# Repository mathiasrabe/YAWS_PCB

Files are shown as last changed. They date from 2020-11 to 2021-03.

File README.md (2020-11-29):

# PCB for IOT weather station

This is the PCB of my small IOT weather station. The weatherstation consists of the following parts:

- ATtiny85 and LT1763-3.3 for power control
- TP4056 to charge the li-ion battery with solar
- BME280 to measure temperature, humidity and pressure
- ESP8266 to connect to WiFi and send the reedings via MQTT

## pictures

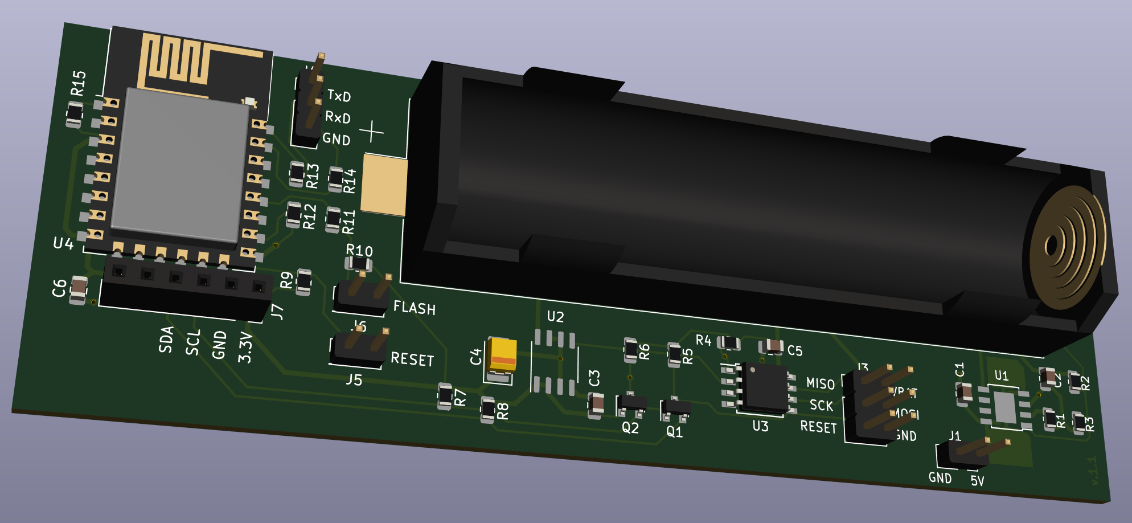
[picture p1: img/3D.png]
3D presentation

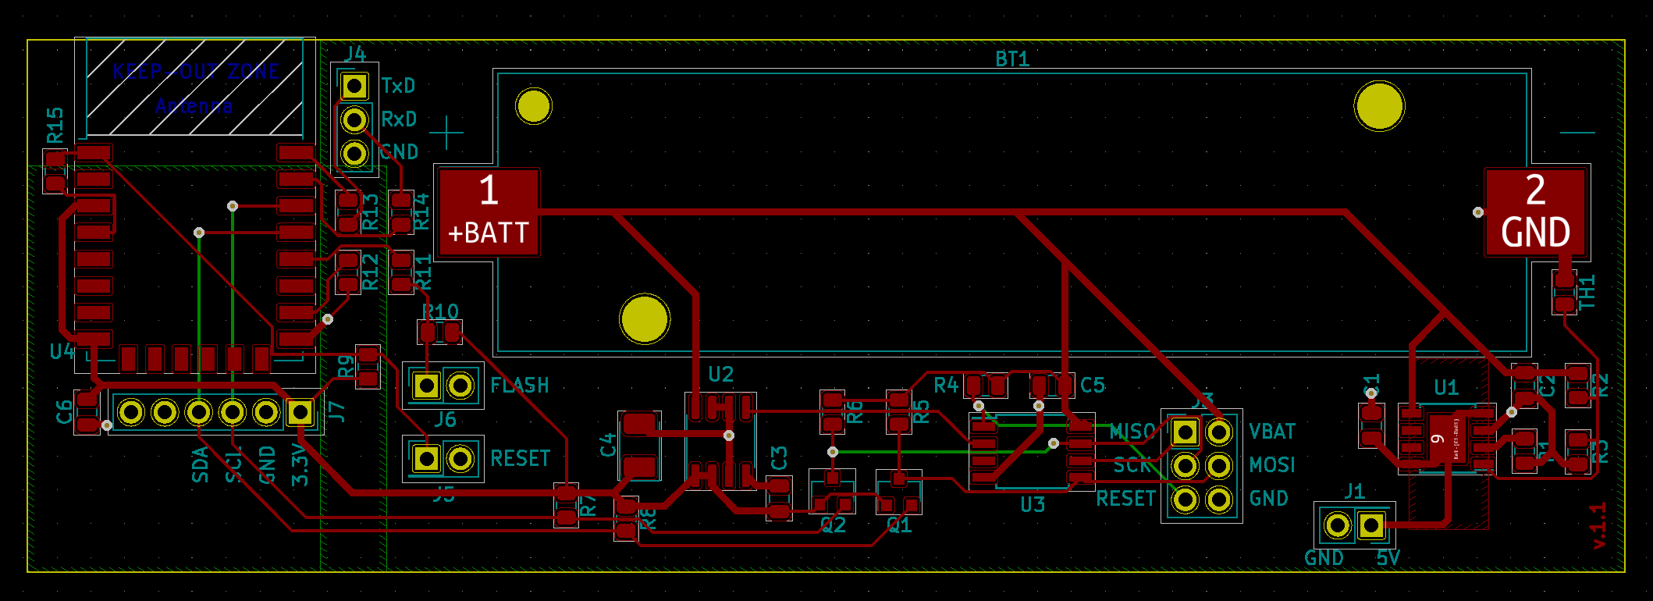
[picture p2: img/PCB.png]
PCB presentation

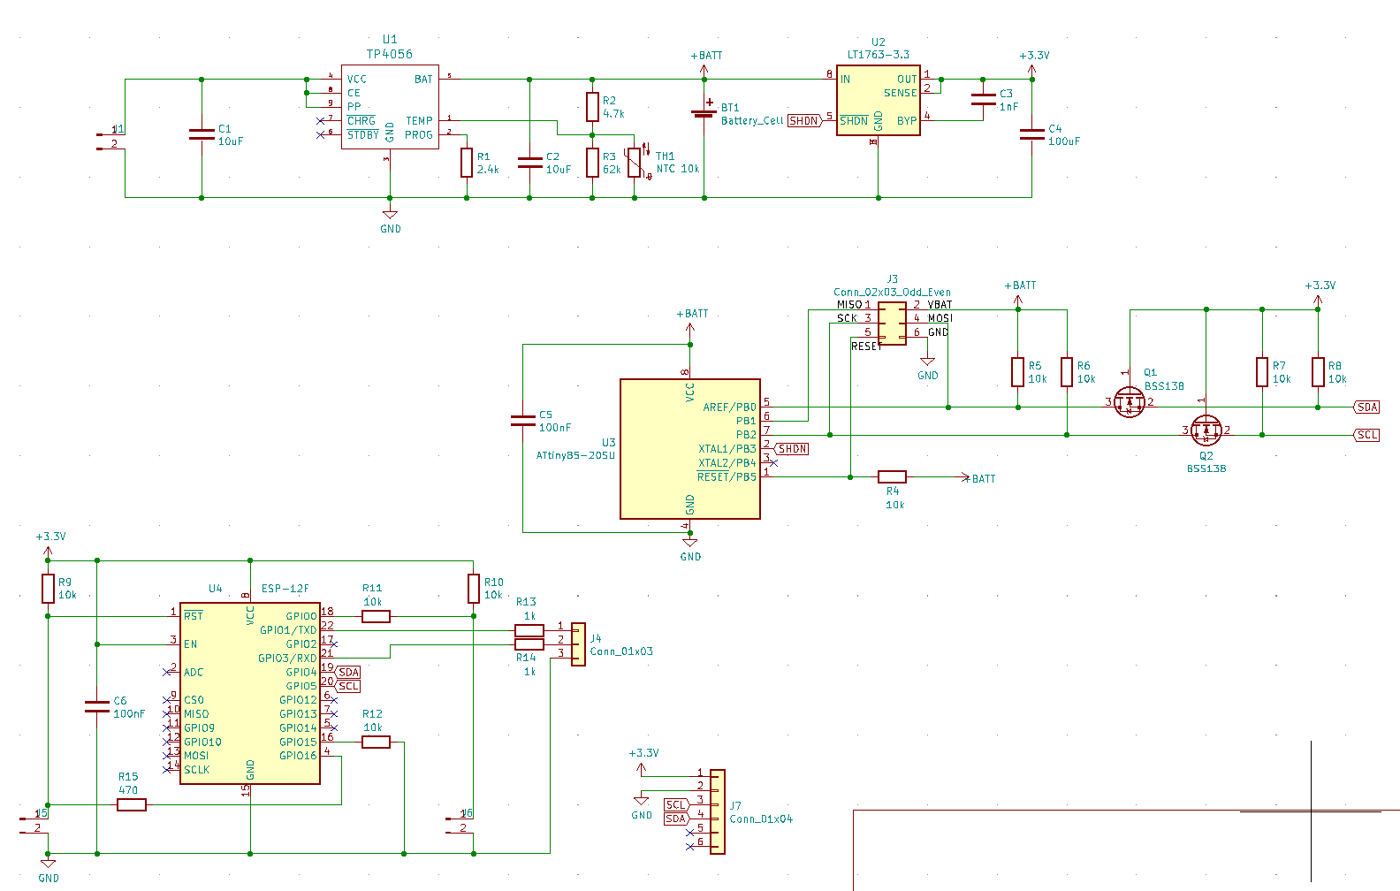
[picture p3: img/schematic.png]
Schematic presentation


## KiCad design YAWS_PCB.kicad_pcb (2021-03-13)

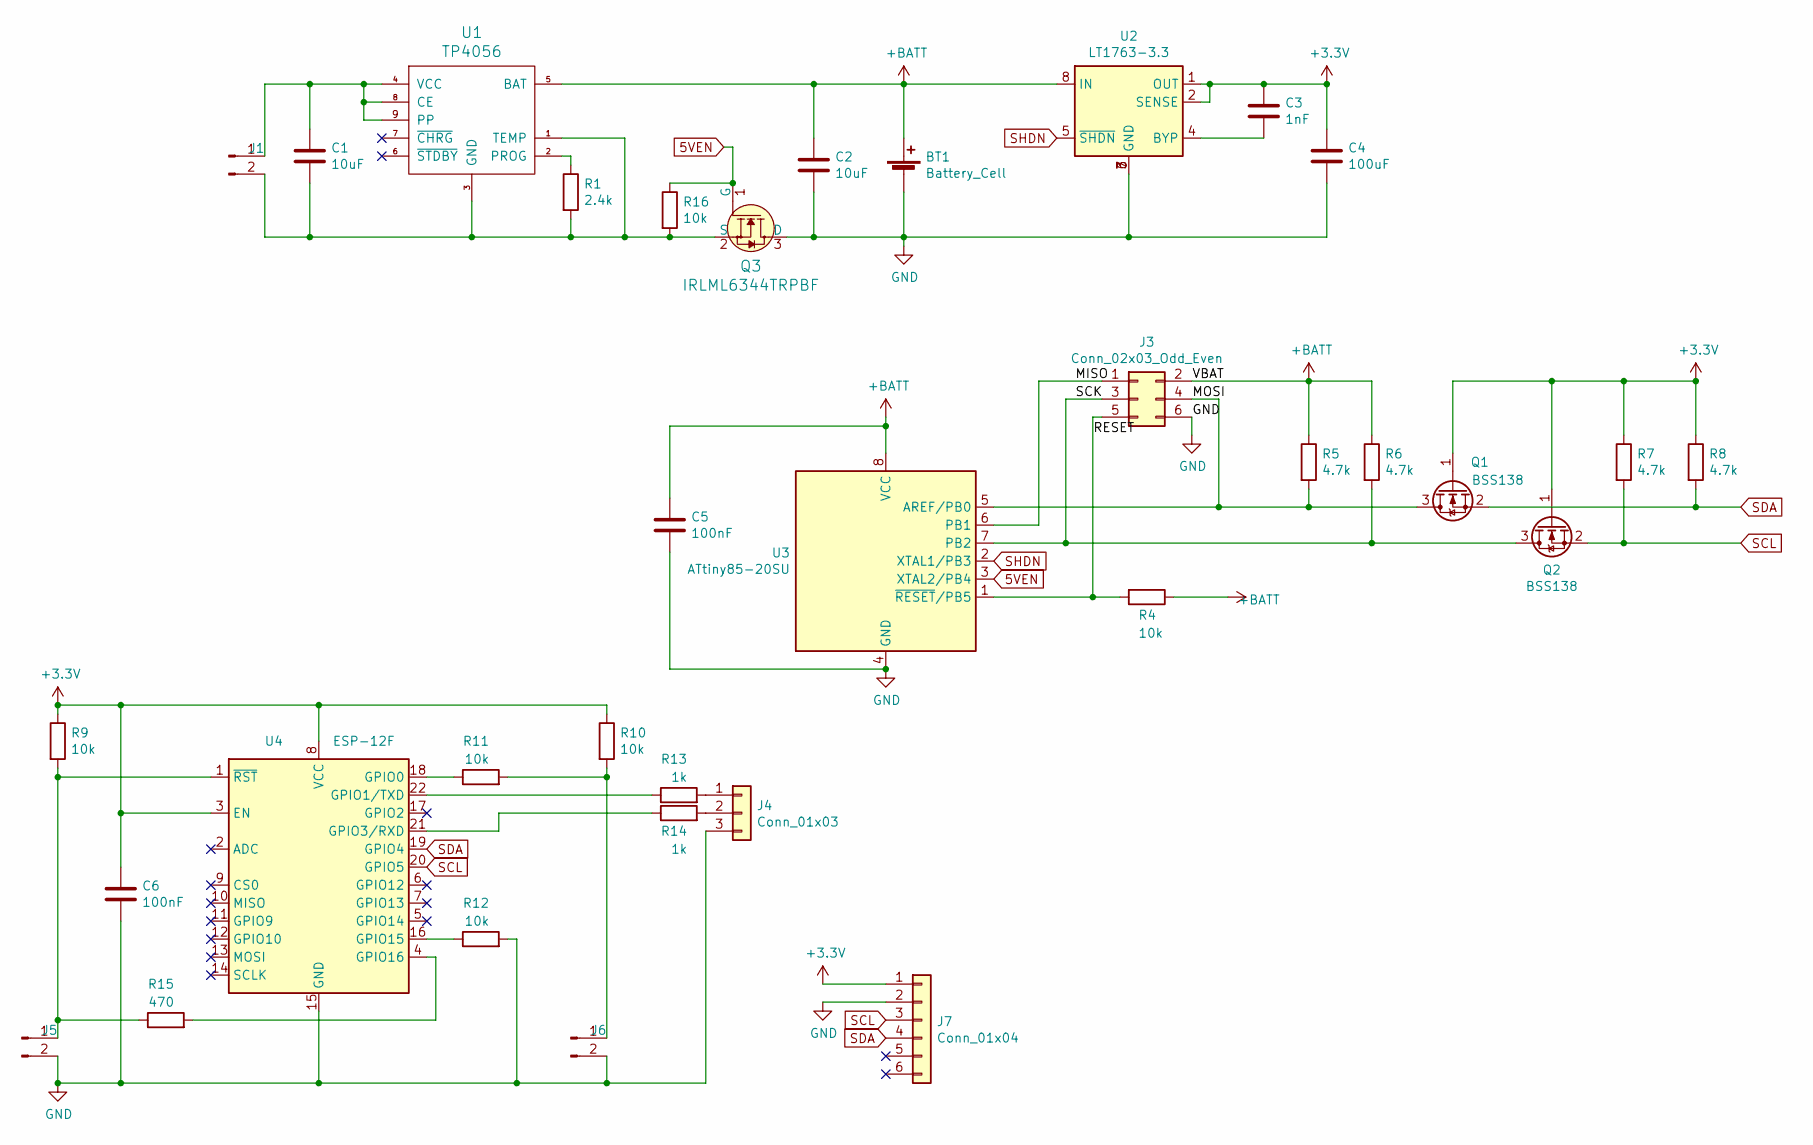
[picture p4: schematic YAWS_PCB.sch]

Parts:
BT1: Battery_Cell; BatteryHolder_Keystone_1042_1x18650
C1, C2: 10uF; C_0805_2012Metric
C3: 1nF; C_0805_2012Metric
C4: 100uF; CP_EIA-3528-21_Kemet-B_Pad1.50x2.35mm_HandSolder
C5, C6: 100nF; C_0805_2012Metric
J1, J5, J6: Conn_01x02_Male; PinHeader_2x01_P2.54mm_Vertical
J3: Conn_02x03_Odd_Even; PinHeader_2x03_P2.54mm_Vertical
J4: Conn_01x03; PinHeader_1x03_P2.54mm_Vertical
J7: Conn_01x04; PinSocket_1x06_P2.54mm_Vertical
Q1, Q2: BSS138; SOT-23
Q3: IRLML6344TRPBF; SOT-23-3; MPN IRLML6344TRPBF; Digi-Key_PN IRLML6344TRPBFCT-ND
R1: 2.4k; R_0805_2012Metric
R4, R9, R10, R11, R12, R16: 10k; R_0805_2012Metric
R5, R6, R7, R8: 4.7k; R_0805_2012Metric
R13, R14: 1k; R_0805_2012Metric
R15: 470; R_0805_2012Metric
U1: TP4056; TP4056_SOP-8-PP
U2: LT1763-3.3; SO-8_3.9x4.9mm_P1.27mm
U3: ATtiny85-20SU; SOIJ-8_5.3x5.3mm_P1.27mm
U4: ESP-12F; ESP-12E

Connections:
5VEN: Q3.1 (G), R16.1, U3.3 (XTAL2/PB4)
+3V3: C3.1, C4.1, C6.1, J7.1, Q1.1 (G), Q2.1 (G), R7.1, R8.1, R9.1, R10.1, U2.1 (OUT), U2.2 (SENSE), U4.3 (EN), U4.8 (VCC)
+BATT: BT1.1 (+), C2.1, C5.1, J3.2, R4.1, R5.1, R6.1, U1.5 (BAT), U2.8 (IN), U3.8 (VCC)
/MISO: J3.1, U3.6 (PB1)
/MOSI: J3.4, Q1.3 (D), R5.2, U3.5 (AREF/PB0)
/RESET: J3.5, R4.2, U3.1 (~RESET~/PB5)
/SCK: J3.3, Q2.3 (D), R6.2, U3.7 (PB2)
GND: BT1.2 (-), C2.2, C4.2, C5.2, C6.2, J3.6, J4.3, J5.2, J6.2, J7.2, Q3.3 (D), R12.2, U2.3 (GND), U2.6 (GND), U2.7 (GND), U3.4 (GND), U4.15 (GND)
unnamed: C1.1, J1.1, U1.4 (VCC), U1.8 (CE), U1.9 (PP)
unnamed: C1.2, J1.2, Q3.2 (S), R1.2, R16.2, U1.1 (TEMP), U1.3 (GND)
unnamed: C3.2, U2.4 (BYP)
unnamed: J4.1, R13.2
unnamed: J4.2, R14.2
unnamed: J5.1, R9.2, R15.1, U4.1 (~RST)
unnamed: J6.1, R10.2, R11.2
unnamed: R1.1, U1.2 (PROG)
unnamed: R11.1, U4.18 (GPIO0)
unnamed: R12.1, U4.16 (GPIO15)
unnamed: R13.1, U4.22 (GPIO1/TXD)
unnamed: R14.1, U4.21 (GPIO3/RXD)
unnamed: R15.2, U4.4 (GPIO16)
SCL: J7.3, Q2.2 (S), R7.2, U4.20 (GPIO5)
SDA: J7.4, Q1.2 (S), R8.2, U4.19 (GPIO4)
SHDN: U2.5 (~SHDN), U3.2 (XTAL1/PB3)

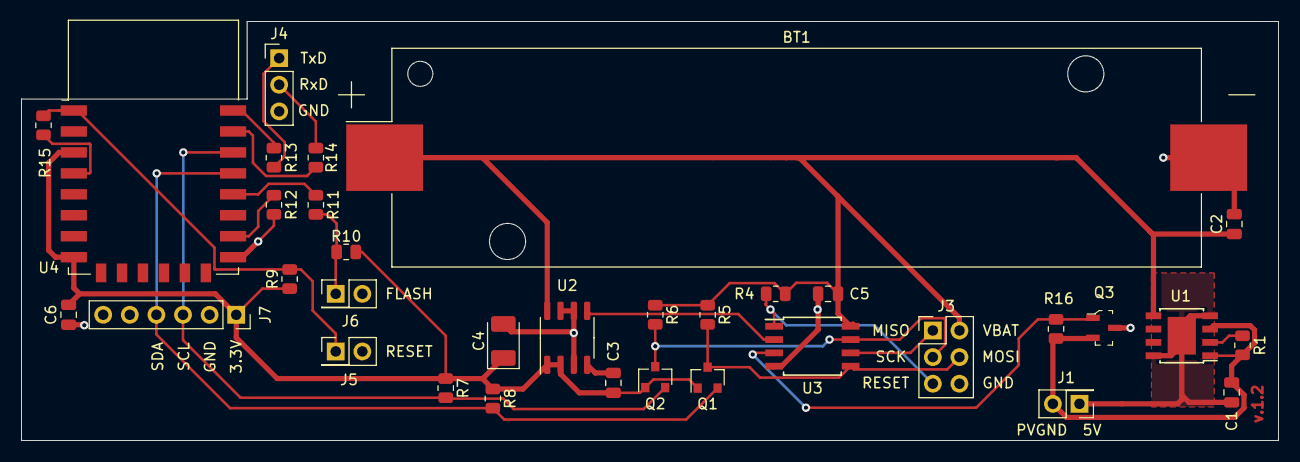
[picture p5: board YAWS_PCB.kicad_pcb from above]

Board: 2 copper layers, 120.0 x 40.0 mm, 34 parts (0 on the bottom side), 24 nets.

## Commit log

2021-02-14 added MOSFET to disconnect TP4056 from battery
    [YAWS_PCB.kicad_pcb, YAWS_PCB.sch]
2021-03-13 reduced I2C pullups
    [YAWS_PCB.kicad_pcb, YAWS_PCB.sch]
